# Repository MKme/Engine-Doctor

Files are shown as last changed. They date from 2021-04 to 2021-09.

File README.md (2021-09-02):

<p align="center">
<b>ESP32 Engine Doctor</b><br>
Use your smartphone web browser to view engine performance and sensor data<br><br>
<br>🐦 <a href="https://twitter.com/mkmeorg">Twitter</a>
| 📺 <a href="https://www.youtube.com/mkmeorg">YouTube</a>
| 🌍 <a href="http://www.mkme.org">mkme.org</a><br>
<br>
Support this project and become a patron on <a href="https://www.patreon.com/EricWilliam">Patreon</a>.<br>
Chat: <a href="https://discord.gg/j9S4Fgv">Discord</a></b>!
</p>

# DIY ESP32 Engine monitoring for all internal combustion engines 
Engine Doc for all chainsaws, small engines and automotive.  

Buy a kit on my store here: https://store.mkme.org/?product=diy-engine-doctor-esp32-egt-engine-tuning-temp-kit

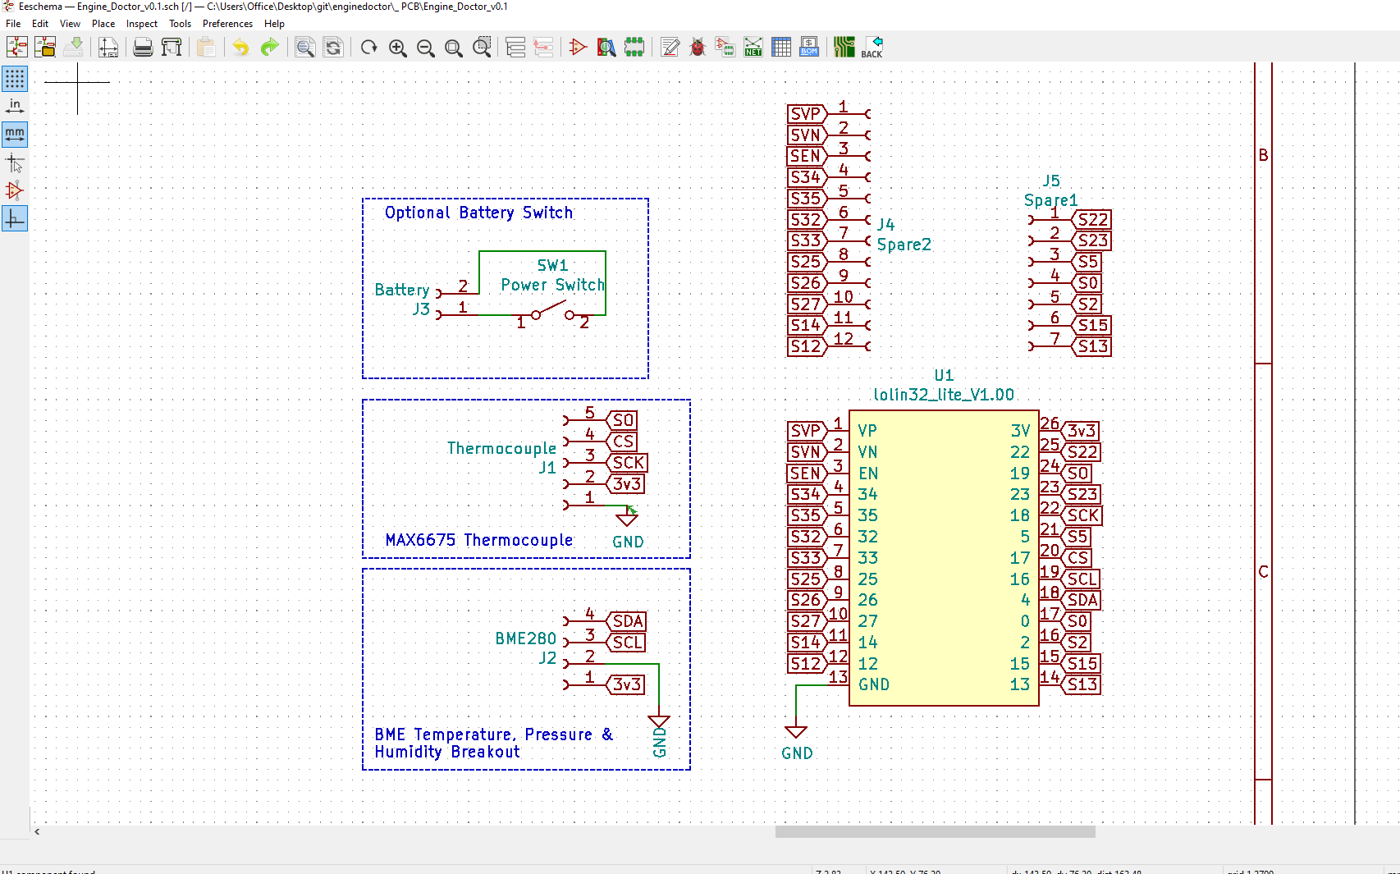
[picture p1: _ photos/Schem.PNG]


## Use Case:
The original ideea is to use this for performance chainsaw tuning by monitoring the EGT (exhaust gas temp) or cylinder/head temp we have valuable information 
we can use to track/correlate our changes and even monitor saws with autotune or needs. 

<p align="center">
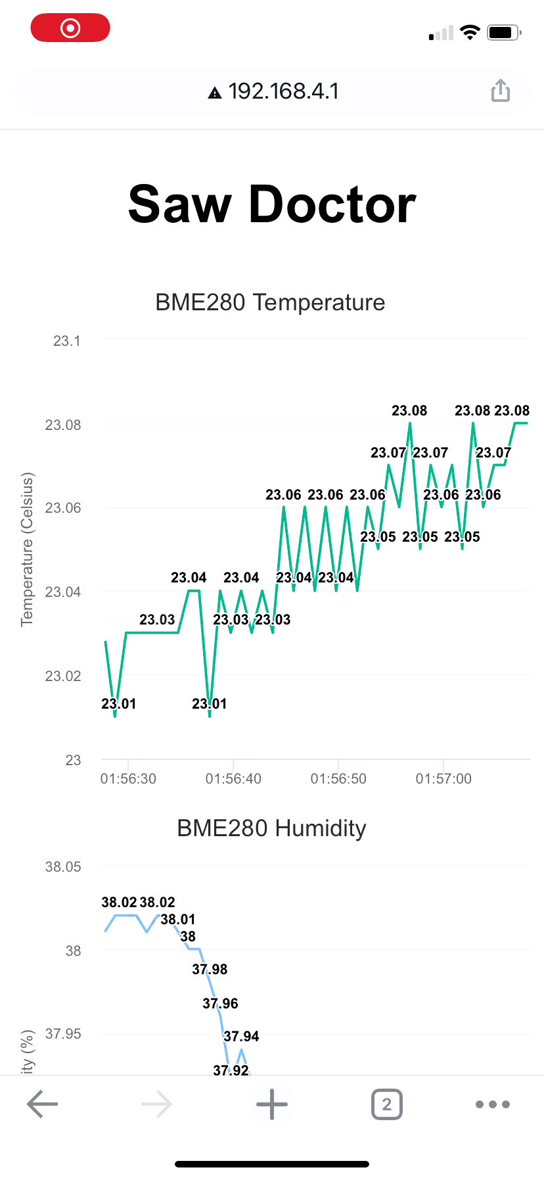
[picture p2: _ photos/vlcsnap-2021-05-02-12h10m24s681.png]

</p>

## Description:

An ESP32 microcontroller with a high temp thermocouple interface you can mount in or stick to any surface you want to measure. 

The ESP32 makes its own Wifi AP (shows up as Engine Doctor wifi network) you can log in to with your phone- open any browser to the IP in the pic and it will graph the data real time asynchronously on the web page as long as its powered on.  

Also has a separate BME280 temp/baro and humidity sensor that will be in the box enclosure or you could remote mount it in an airbox or anywhere you desire.

Future Expansion- I may make a one-wire inductive tachometer pickup too which will be interrupt driven and may need amp circuit. All the spare GPIO are broken out on the PCB for this. 
Lipo battery plugs in to ESP32 and is charged by USB https://amzn.to/3kI5tL8

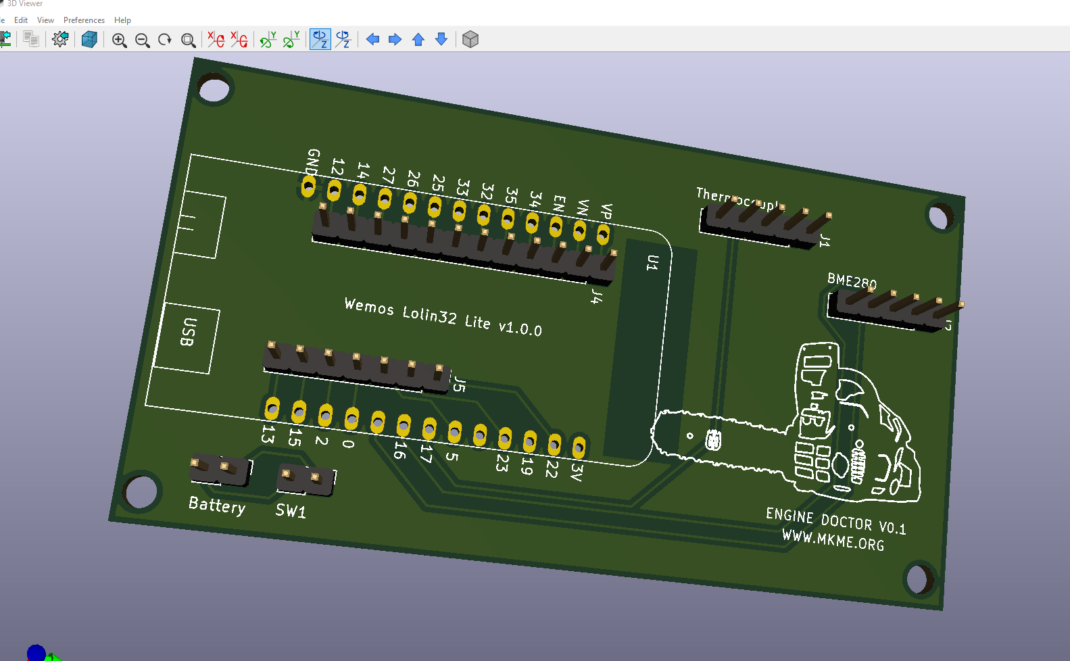
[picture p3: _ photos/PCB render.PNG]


## Parts:

Buy a kit on my store here: https://store.mkme.org/?product=diy-engine-doctor-esp32-egt-engine-tuning-temp-kit

| Component | Source  |
| --- |---|
| ESP32 Wemos 32 Lite V1 | https://amzn.to/2QzS8t3
| MAX 6675 Thermocouple | https://amzn.to/3tyqds0
| BME280 | https://amzn.to/3x99uhg
| BMP280 (cheaper) | https://amzn.to/3kTSyYb

### Full video here:

https://www.youtube.com/watch?v=tzVUzIC2Xmo

### Assembly

- Solder BME 280- note SDC pin (furthest from VCC) is not used- Cut the pin or remove from header

- Use female headers (not supplied in kit) if you would like to make the components removeable

### Code

- Two flavours of code are now offered:

1.  BME280 Version- This has Temp, Pressure and HUMIDITY with Thermocouple

2.  BMP280 Version - This uses the cheaper BMP280 sensor without HUMIDITY

To upload the code you must install ESP32 board support- Google for tutorials

You must be using a fairly recent Arduino IDE to upload spiffs (the web page files)  

Set up your IDE using these settings for the board:

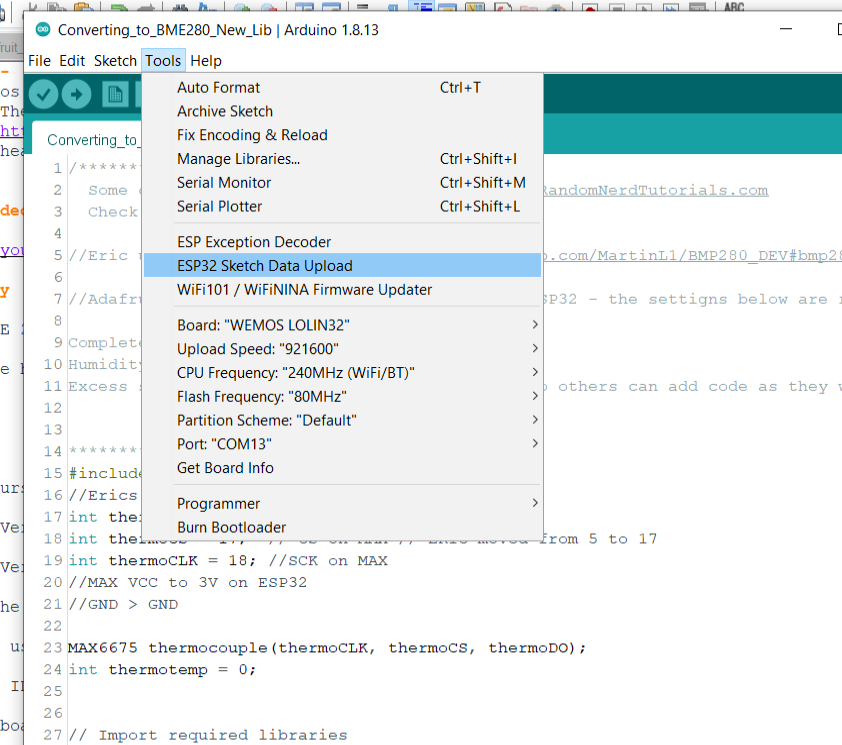
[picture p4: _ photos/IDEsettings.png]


Upload the board (if you get any errors make sure you have installed the Adafruit libraries for the BMP or for BMP280: https://github.com/MartinL1/BMP280_DEV#bmp280_dev_library

Upload web page files Spiffs using the command "Tools> ESP32 Sketch Data Upload"

### How to Use It

- Install the thermocouple where you would like to monitor (use a magnet mount if desired) 

- Power on the EngineDoctor

- Connect to EngineDoctor Wifi with your phone or tablet (no password required)

- Open your web broswer to this url:  192.168.4.1

- Watch the live values in real time while you test/tune!

- Adjust the code if desired to alter the sample display rate (currently 1hz) 

### How I did things (reference) :

Export PCB Footprint to make a case in fusion: https://forum.kicad.info/t/kicad-to-dxf-or-dwg/7994/2

Make the case in fusion: https://www.youtube.com/watch?v=mhXUqtS4mDg&ab_channel=FixedUntilBroken

Make an awesome snap fit case - Thanks Noe! https://www.youtube.com/watch?v=VVmOtM60VWw&ab_channel=AdafruitIndustries

### ESP32 Pinout: 

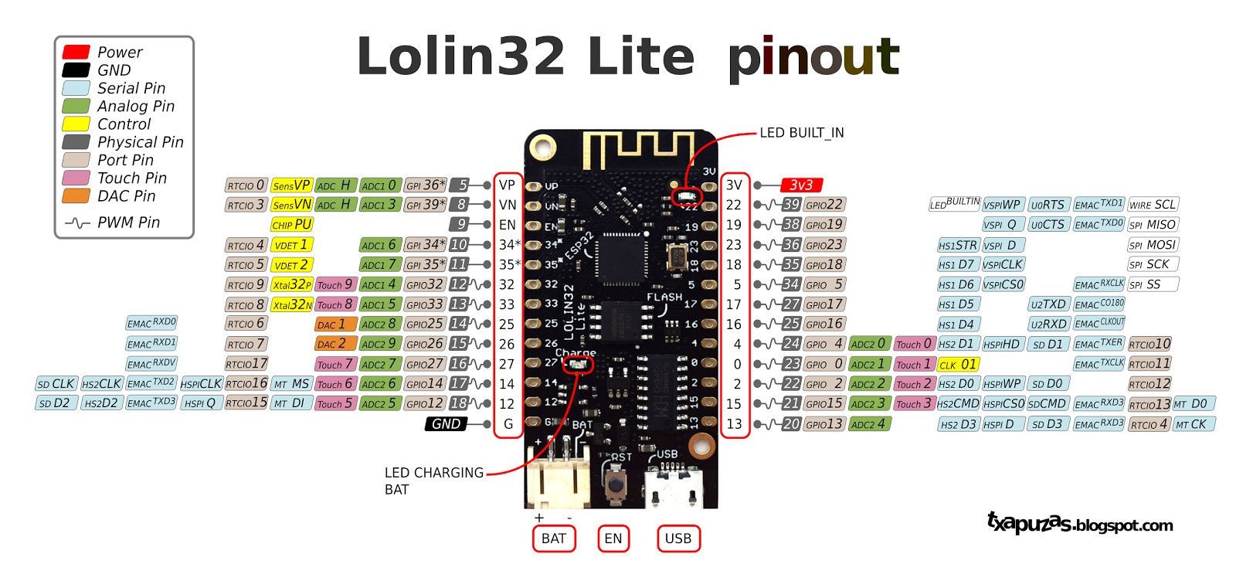
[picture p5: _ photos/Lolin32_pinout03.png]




This work is licensed under a Creative Commons Attribution-NonCommercial 4.0 International License. https://creativecommons.org/licenses/by-nc/4.0/ See comments in main code for more info

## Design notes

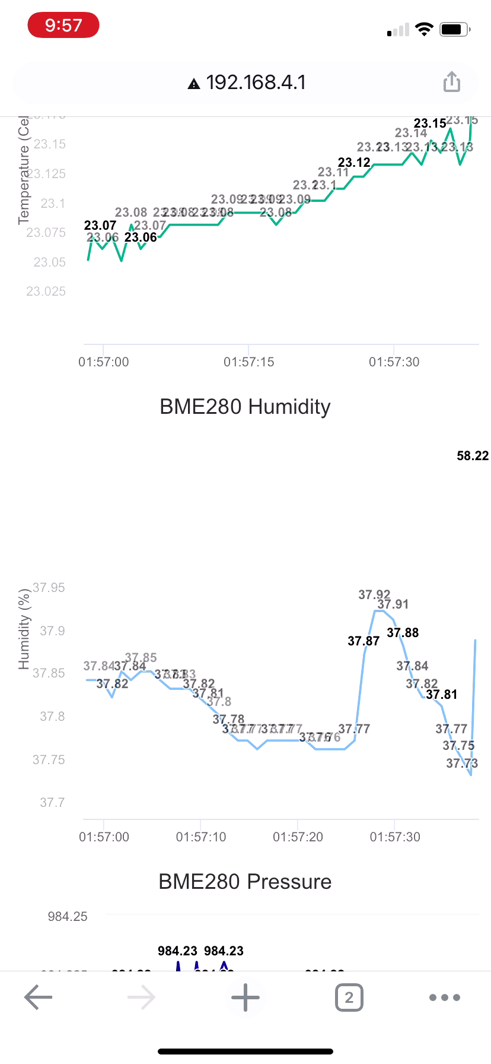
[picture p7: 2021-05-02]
_ photos/vlcsnap-2021-05-02-12h10m46s337.png

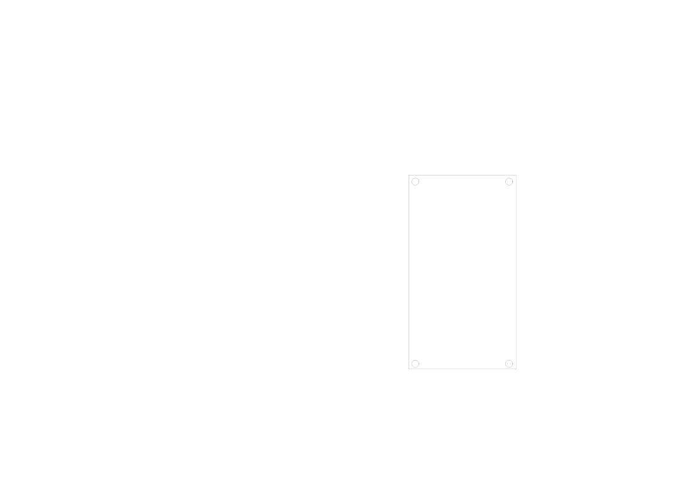
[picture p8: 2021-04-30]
_ Enclosure/Engine_Doctor_v0.1-Edge_Cuts.jpg

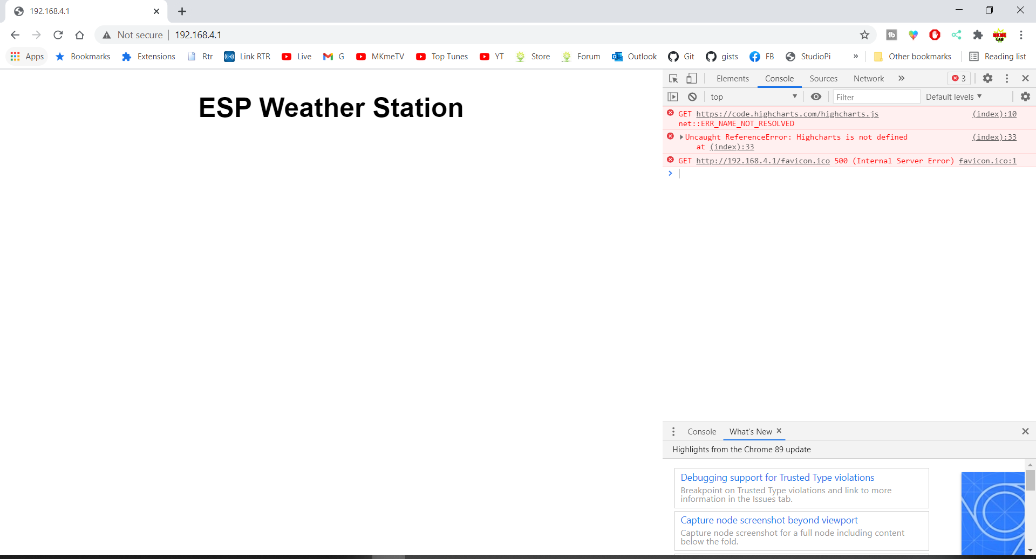
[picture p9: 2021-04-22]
_ photos/desktop error.PNG

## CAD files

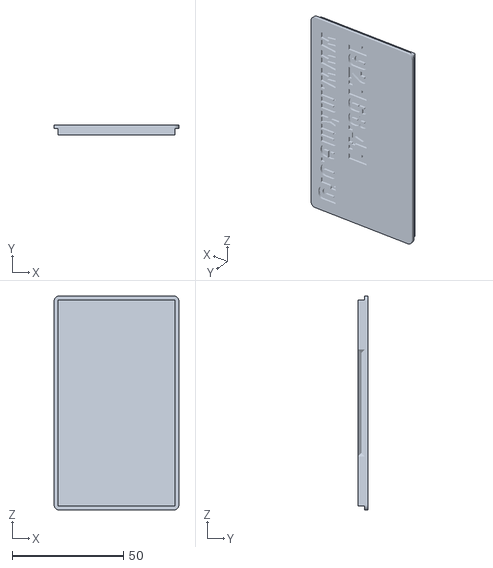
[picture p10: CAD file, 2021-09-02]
_ Enclosure/Top.stl
56.0 x 4.50 x 96.0

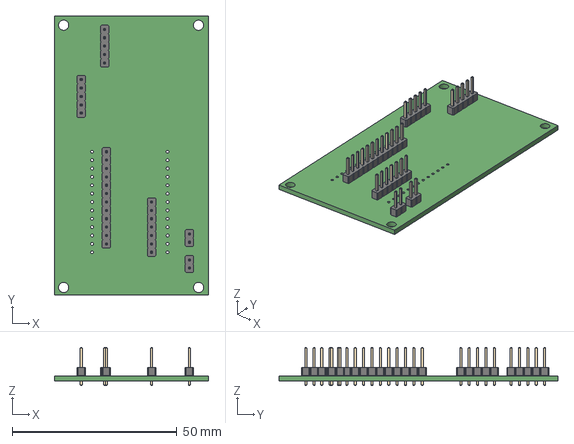
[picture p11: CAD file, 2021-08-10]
_ PCB/Engine_Doctor_v0.1/Engine_Doctor_v0.1.step
46.7 x 84.6 x 11.5 mm

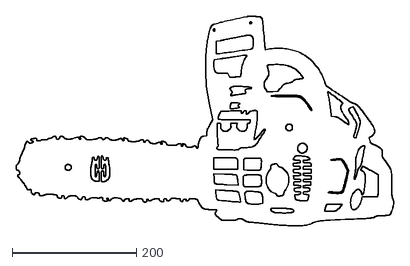
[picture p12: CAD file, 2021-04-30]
_ photos/Chainsaw_Design_9_17_7_x_9_9_inches_x700.dxf
607.7 x 337.4

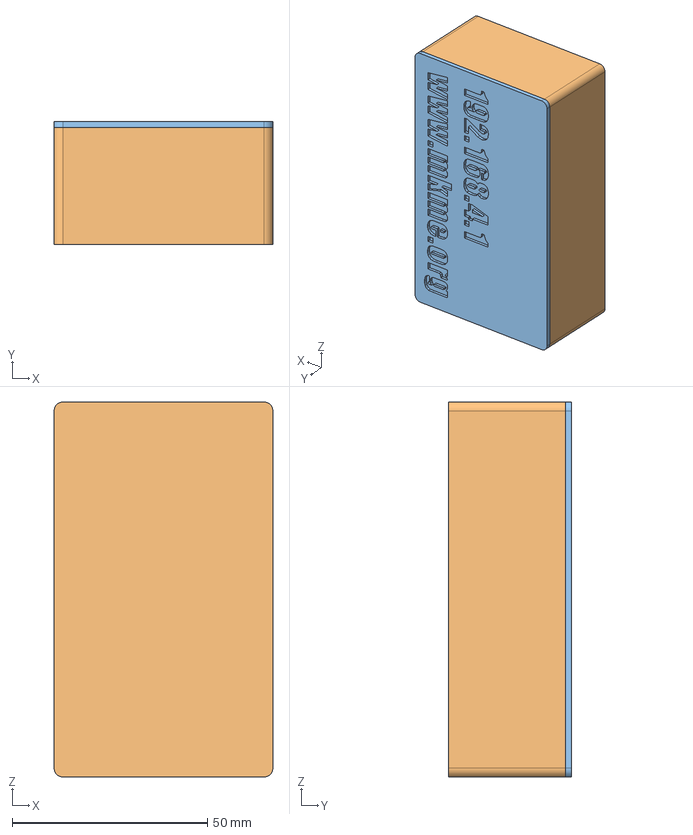
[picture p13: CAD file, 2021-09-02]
_ Enclosure/Engine Doctor V0.1 v9.step
56.0 x 31.5 x 96.0 mm
Bottom
Top

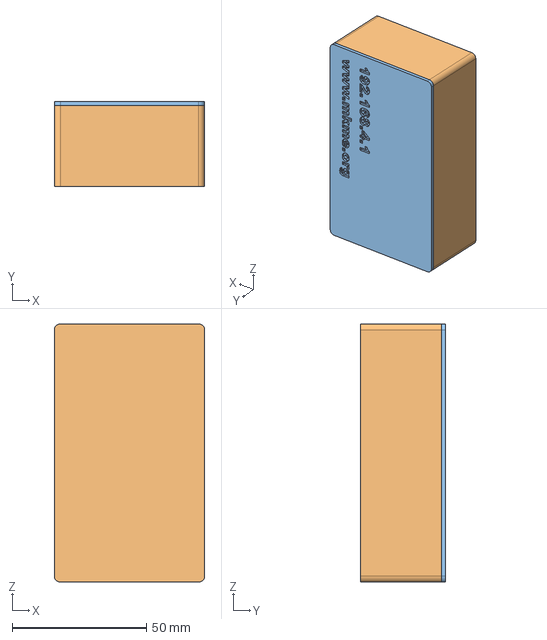
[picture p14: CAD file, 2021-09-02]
_ Enclosure/Engine Doctor V0.1 v8.step
56.0 x 31.5 x 96.0 mm
Bottom
Top

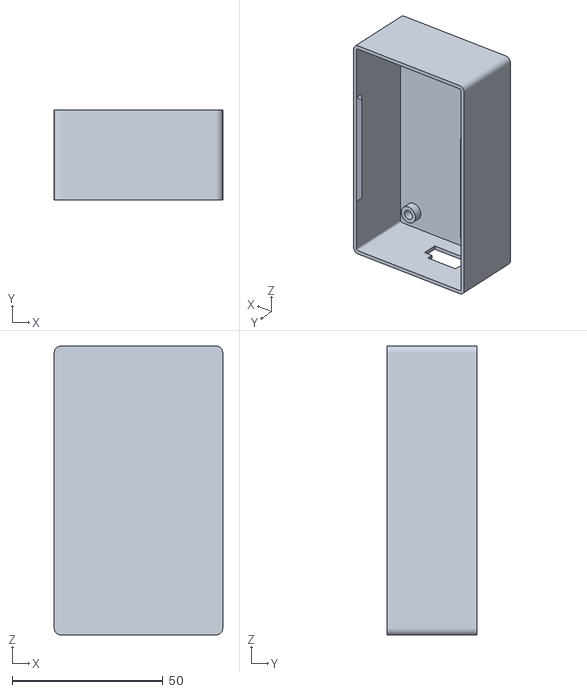
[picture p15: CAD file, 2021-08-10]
_ Enclosure/Bottom.stl
56.0 x 30.0 x 96.0

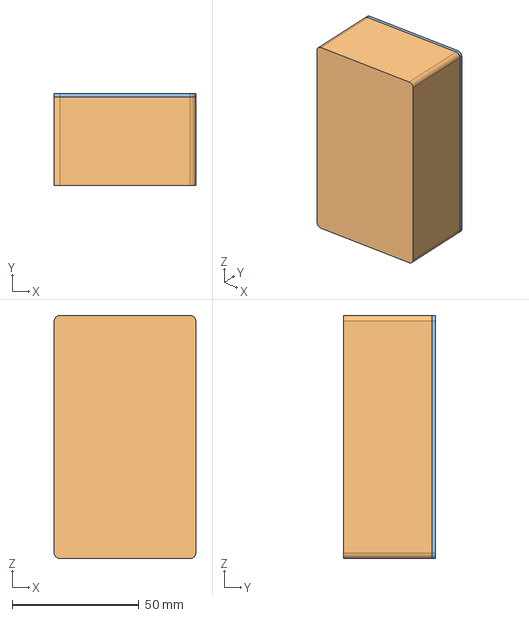
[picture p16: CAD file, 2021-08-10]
_ Enclosure/Engine Doctor V0.1 v2.step
56.0 x 36.5 x 96.0 mm
Bottom
Top

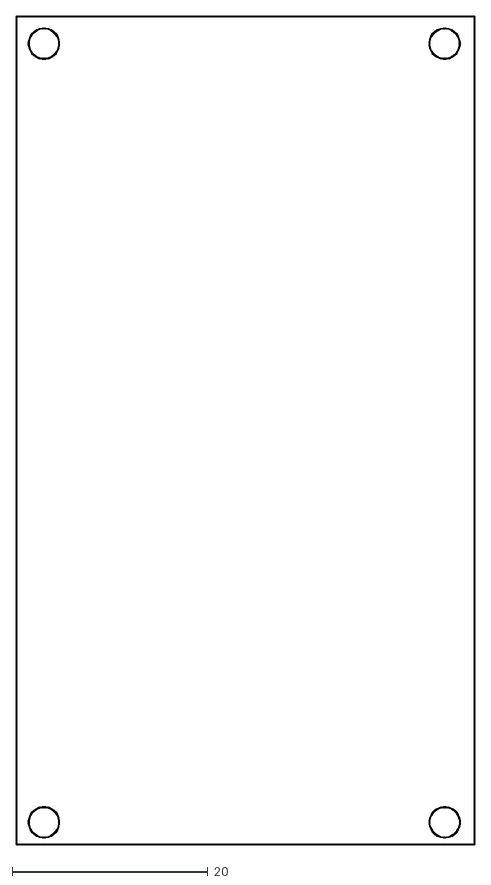
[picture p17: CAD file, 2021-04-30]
_ Enclosure/Engine_Doctor_v0.1-Edge_Cuts.dxf
46.8 x 84.6

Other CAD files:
_ Enclosure/Engine Doctor V0.1 v5.step

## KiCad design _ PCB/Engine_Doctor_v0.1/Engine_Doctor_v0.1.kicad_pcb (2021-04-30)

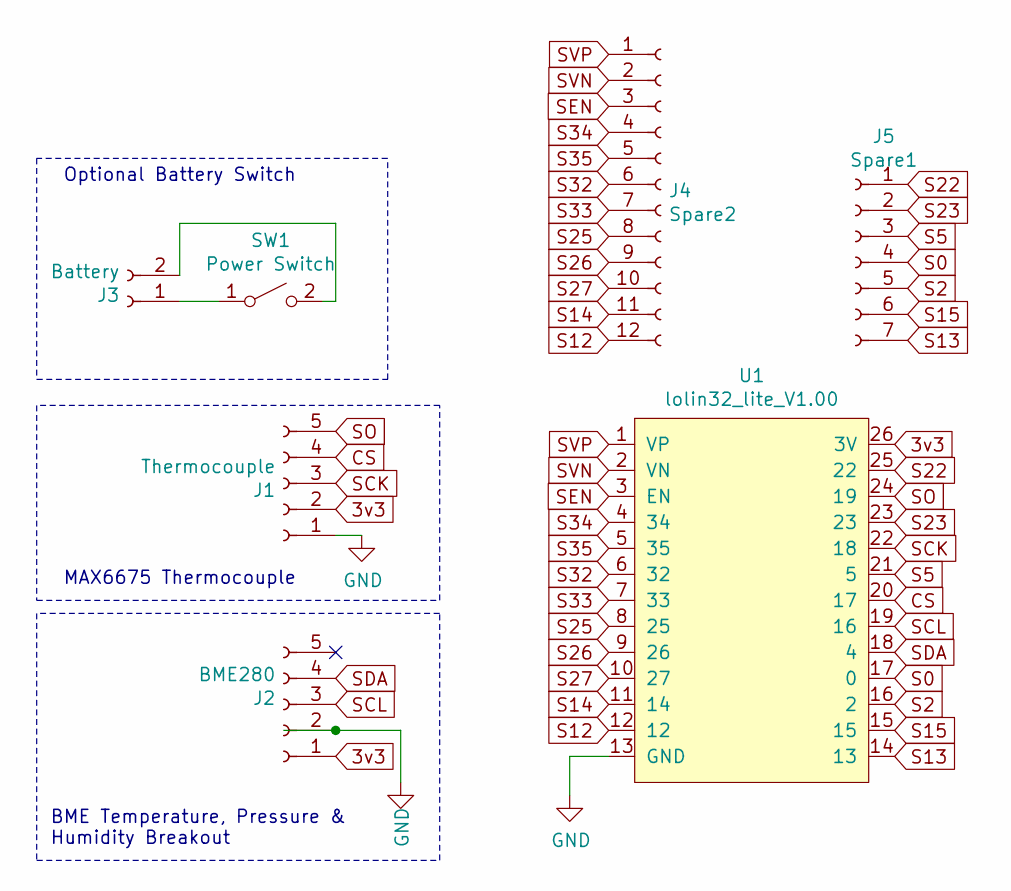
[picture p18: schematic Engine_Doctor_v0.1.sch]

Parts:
J1: Thermocouple; PinHeader_1x05_P2.54mm_Vertical
J2: BME280; PinHeader_1x05_P2.54mm_Vertical
J3: Battery; PinHeader_1x02_P2.54mm_Vertical
J4: Spare2; PinHeader_1x12_P2.54mm_Vertical
J5: Spare1; PinHeader_1x07_P2.54mm_Vertical
SW1: Power Switch; PinHeader_1x02_P2.54mm_Vertical
U1: lolin32_lite_V1.00; lolin32_lite

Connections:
3v3: J1.2, J2.1, U1.26 (3V)
CS: J1.4, U1.20 (17)
GND: J1.1, J2.2, U1.13 (GND)
unnamed: J3.1, SW1.1 (A)
unnamed: J3.2, SW1.2 (B)
S0: J5.4, U1.17 (0)
S2: J5.5, U1.16 (2)
S5: J5.3, U1.21 (5)
S12: J4.12, U1.12
S13: J5.7, U1.14 (13)
S14: J4.11, U1.11 (14)
S15: J5.6, U1.15
S22: J5.1, U1.25 (22)
S23: J5.2, U1.23
S25: J4.8, U1.8 (25)
S26: J4.9, U1.9 (26)
S27: J4.10, U1.10 (27)
S32: J4.6, U1.6 (32)
S33: J4.7, U1.7 (33)
S34: J4.4, U1.4 (34)
S35: J4.5, U1.5 (35)
SCK: J1.3, U1.22 (18)
SCL: J2.3, U1.19 (16)
SDA: J2.4, U1.18 (4)
SEN: J4.3, U1.3 (EN)
SO: J1.5, U1.24 (19)
SVN: J4.2, U1.2 (VN)
SVP: J4.1, U1.1 (VP)

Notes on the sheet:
Optional Battery Switch
BME Temperature, Pressure & Humidity Breakout
MAX6675 Thermocouple

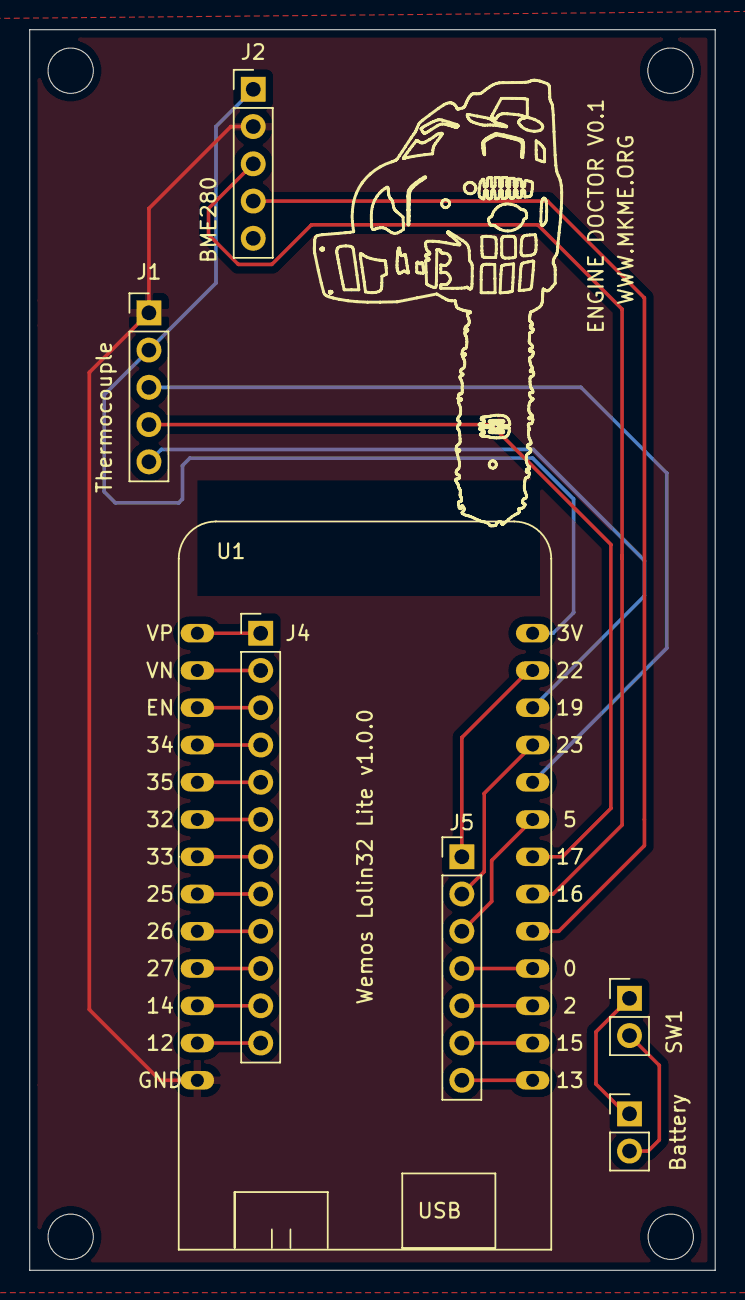
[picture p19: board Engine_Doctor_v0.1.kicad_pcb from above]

Board: 2 copper layers, 46.7 x 84.6 mm, 7 parts (0 on the bottom side), 28 nets.

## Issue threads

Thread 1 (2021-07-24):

BMP 280 Not Working- Yet

MKme, 2021-07-24:
Sensor is detected on I2C bus but will not communicate with existing code examples. Likely hardware is different than standard BMP280 but address is correct at 0X76 (confirmed found with I2C scanner sketch)

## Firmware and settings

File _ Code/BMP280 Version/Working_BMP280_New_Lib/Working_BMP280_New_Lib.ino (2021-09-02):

/*********
My Youtube Channel  : http://www.youtube.com/mkmeorg
If you use this code or personalize it etc- please consider sharing it back with the world via the forum at http://www.mkme.org/forum
Website, Forum http://mkme.org
Chat with Me: Discord http://mkme.org/discord
Store http://mkme.org/store
Buy a parts kit on my store: https://store.mkme.org/?product=diy-engine-doctor-esp32-egt-engine-tuning-temp-kit  
  
Some code adapted from Rui Santos at https://RandomNerdTutorials.com
Check out his site and give him some support

Eric used Martins Library here: https://github.com/MartinL1/BMP280_DEV#bmp280_dev_library

Adafruit library just refused to work on my ESP32 - the settings below are reading yay!    

Completely working with BMP280 now!!!  
Humidity display removed
Excess serial debugging is left in place here so others can add code as they want for IO etc

  
*********/
#include "max6675.h"
//Erics confirmed pins for the LOLIN 32 lite 
int thermoDO = 19;  //SO on MAX breakout 
int thermoCS = 17;  // CS on MAX // ERIC moved from 5 to 17 
int thermoCLK = 18; //SCK on MAX 
//MAX VCC to 3V on ESP32
//GND > GND 

MAX6675 thermocouple(thermoCLK, thermoCS, thermoDO);
int thermotemp = 0;


// Import required libraries
#ifdef ESP32
  #include <WiFi.h>
  #include <ESPAsyncWebServer.h>
  #include <SPIFFS.h>
  #include <arduino.h>
#else
  #include <Arduino.h>
  #include <ESP8266WiFi.h>
  #include <Hash.h>
  #include <ESPAsyncTCP.h>
  #include <ESPAsyncWebServer.h>
  #include <FS.h>
#endif
#include <Wire.h>
#include <Adafruit_Sensor.h>
#include <Adafruit_BME280.h>

/*#include <SPI.h>
#define BME_SCK 18
#define BME_MISO 19
#define BME_MOSI 23
#define BME_CS 5*/

#include <BMP280_DEV.h>  
// Added these defines myself from code I cound for ESP32 cam here: https://3iinc.xyz/blog/how-to-use-i2c-sensor-bme280-with-esp32cam/
#define I2C_SDA 4 
#define I2C_SCL 16
TwoWire I2CSensors = TwoWire(0);  //not sure if this is actually needed :)  
float temperature, pressure, altitude;            // Create the temperature, pressure and altitude variables
BMP280_DEV bmp280(4, 16);                        // Instantiate (create) a BMP280 object and set-up for I2C operation on pins SDA: A6, SCL: A7



// Name the Network SSID and give it a password if you desire 
const char* ssid     = "EngineDoctor";
const char* password = "";

// Create AsyncWebServer object on port 80
AsyncWebServer server(80);

  
String readBMP280Temperature() {
  // Read temperature as Celsius (the default)
  float t = (temperature);
  if (isnan(t)) {    
    Serial.println("Failed to read from BMP280 sensor!");
    return "";
  }
  else {
    Serial.print("BMP Temp   C   ");
    Serial.println(t);
    return String(t);
  }
}


String readBMP280Pressure() {
  float p = (pressure);
  if (isnan(p)) {
    Serial.println("Failed to read from BMP280 sensor!");
    return "";
  }
  else {
    Serial.println(p);
    return String(p);
  }
}

String readthermocouple() {
  float thermocouple1 = thermocouple.readCelsius();
  if (isnan(thermocouple1)) {
    Serial.println("Failed to read from thermocouple sensor!");
    return "";
  }
  else {
    Serial.println(thermocouple1);
    return String(thermocouple1);
  }
}



void setup(){

  I2CSensors.begin(I2C_SDA, I2C_SCL, 100000);
    bmp280.begin(BMP280_I2C_ALT_ADDR);
  // Serial port for debugging purposes
  Serial.begin(115200);                           // Initialise the serial port
  //bmp280.begin();                                 // Default initialisation, place the BMP280 into SLEEP_MODE 
  bmp280.setTimeStandby(TIME_STANDBY_2000MS);     // Set the standby time to 2 seconds
  bmp280.startNormalConversion();                 // Start BMP280 continuous conversion in NORMAL_MODE




    Serial.println("MAX6675 test");
  // wait for MAX chip to stabilize
thermotemp = thermocouple.readCelsius();
   Serial.print("C = "); 
   Serial.println(thermocouple.readCelsius());
   
 
   Serial.println(thermotemp);
   Serial.print("F = ");
   Serial.println(thermocouple.readFahrenheit());

  // Initialize SPIFFS
  if(!SPIFFS.begin()){
    Serial.println("An Error has occurred while mounting SPIFFS");
    return;
  }

  // Connect to Wi-Fi
    WiFi.softAP(ssid, password);
  IPAddress IP = WiFi.softAPIP();
  Serial.print("AP IP address: ");
  Serial.println(IP);
  WiFi.setSleep(WIFI_PS_NONE);
 // server.begin();   // Dunno where this came from- commented out but no improvement much sad 



  // Route for root / web page
  server.on ("/", HTTP_GET, [](AsyncWebServerRequest *request){
    request->send(SPIFFS, "/index.html");
  });




 
  server.on ("/temperature", HTTP_GET, [](AsyncWebServerRequest *request){
    request->send_P(200, "text/plain", readBMP280Temperature().c_str());
  });
  
  server.on ("/pressure", HTTP_GET, [](AsyncWebServerRequest *request){
    request->send_P(200, "text/plain", readBMP280Pressure().c_str());
  });

  server.on ("/thermocouple", HTTP_GET, [](AsyncWebServerRequest *request){
    request->send_P(200, "text/plain", readthermocouple().c_str());
  });

  // Start server
  server.begin();
}
 
void loop(){
  if (bmp280.getMeasurements(temperature, pressure, altitude))    // Check if the measurement is complete
  {
    Serial.print(temperature);                    // Display the results    
    Serial.print(F("*C   "));
    Serial.print(pressure);    
    Serial.print(F("hPa   "));
    Serial.print(altitude);
    Serial.println(F("m"));  
  }
  
}

//This work is licensed under a Creative Commons Attribution-NonCommercial 4.0 International License. https://creativecommons.org/licenses/by-nc/4.0/ See comments in main code for more info

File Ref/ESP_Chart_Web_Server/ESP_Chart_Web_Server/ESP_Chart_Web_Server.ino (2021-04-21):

/*********
  Rui Santos
  Complete project details at https://RandomNerdTutorials.com
  
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
  The above copyright notice and this permission notice shall be included in all
  copies or substantial portions of the Software.
*********/

// Import required libraries
#ifdef ESP32
  #include <WiFi.h>
  #include <ESPAsyncWebServer.h>
  #include <SPIFFS.h>
#else
  #include <Arduino.h>
  #include <ESP8266WiFi.h>
  #include <Hash.h>
  #include <ESPAsyncTCP.h>
  #include <ESPAsyncWebServer.h>
  #include <FS.h>
#endif
#include <Wire.h>
#include <Adafruit_Sensor.h>
#include <Adafruit_BME280.h>

/*#include <SPI.h>
#define BME_SCK 18
#define BME_MISO 19
#define BME_MOSI 23
#define BME_CS 5*/

Adafruit_BME280 bme; // I2C
//Adafruit_BME280 bme(BME_CS); // hardware SPI
//Adafruit_BME280 bme(BME_CS, BME_MOSI, BME_MISO, BME_SCK); // software SPI

// Replace with your network credentials
const char* ssid = "";
const char* password = "";

// Create AsyncWebServer object on port 80
AsyncWebServer server(80);

String readBME280Temperature() {
  // Read temperature as Celsius (the default)
  float t = bme.readTemperature();
  // Convert temperature to Fahrenheit
  //t = 1.8 * t + 32;
  if (isnan(t)) {    
    Serial.println("Failed to read from BME280 sensor!");
    return "";
  }
  else {
    Serial.println(t);
    return String(t);
  }
}

String readBME280Humidity() {
  float h = bme.readHumidity();
  if (isnan(h)) {
    Serial.println("Failed to read from BME280 sensor!");
    return "";
  }
  else {
    Serial.println(h);
    return String(h);
  }
}

String readBME280Pressure() {
  float p = bme.readPressure() / 100.0F;
  if (isnan(p)) {
    Serial.println("Failed to read from BME280 sensor!");
    return "";
  }
  else {
    Serial.println(p);
    return String(p);
  }
}

void setup(){
  // Serial port for debugging purposes
  Serial.begin(115200);
  


  // Initialize SPIFFS
  if(!SPIFFS.begin()){
    Serial.println("An Error has occurred while mounting SPIFFS");
    return;
  }

  // Connect to Wi-Fi
  WiFi.begin(ssid, password);
  while (WiFi.status() != WL_CONNECTED) {
    delay(1000);
    Serial.println("Connecting to WiFi..");
  }

  // Print ESP32 Local IP Address
  Serial.println(WiFi.localIP());

  // Route for root / web page
  server.on("/", HTTP_GET, [](AsyncWebServerRequest *request){
    request->send(SPIFFS, "/index.html");
  });
  server.on("/temperature", HTTP_GET, [](AsyncWebServerRequest *request){
    request->send_P(200, "text/plain", readBME280Temperature().c_str());
  });
  server.on("/humidity", HTTP_GET, [](AsyncWebServerRequest *request){
    request->send_P(200, "text/plain", readBME280Humidity().c_str());
  });
  server.on("/pressure", HTTP_GET, [](AsyncWebServerRequest *request){
    request->send_P(200, "text/plain", readBME280Pressure().c_str());
  });

  // Start server
  server.begin();
}
 
void loop(){
  
}

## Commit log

2021-04-20 Revised alllllllllllllll
    [Engine_Doctor_v0.1.kicad_pcb, Engine_Doctor_v0.1.sch, Lolin32 lite_2021-04-20.kicad_pcb]
2021-04-22 Temporarily disabled BME
    BME is what was crashing ESP- commented out triggers
    [ESP_Chart_Web_Server_Converted_into_AP_Works_ERIC__Adding_Therm.ino]
2021-04-23 Updated with Lolin board files
    [Engine_Doctor_v0.1.kicad_pcb, Engine_Doctor_v0.1.sch]
2021-04-30 V0.1 PCB Design Complete
    [Engine_Doctor_v0.1.kicad_pcb, Lolin32 lite_2021-04-20.kicad_pcb]
2021-04-30 PCB completed
    [Bottom.stl, Chainsaw_Design_9_17_7_x_9_9_inches_x700.dxf, Engine_Doctor_v0.1-Edge_Cuts.dxf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]
2021-04-30 Create Engine Doctor V0.1 v2.step
    [Engine Doctor V0.1 v2.step]
2021-08-10 New case
    [Bottom.stl, Engine Doctor V0.1 v2.step, Engine Doctor V0.1 v5.step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]
